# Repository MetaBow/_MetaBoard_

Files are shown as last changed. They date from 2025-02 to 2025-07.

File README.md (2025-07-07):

# MetaBoard™

Buy Now (https://www.paypal.com/ncp/payment/BA7CCF7549GLA)

# MetaBoard

Board_mount-ezgif com-video-to-gif-converter

### Main ICs

- Micro: [nRF53240](https://www.nordicsemi.com/Products/nRF5340) in the [MDBT53](https://www.raytac.com/download/index.php?index_id=60) module
- PMIC (Power manangement IC): [nPM1100](https://www.nordicsemi.com/Products/nPM1100)
- IMU: [BNO086](https://www.ceva-ip.com/wp-content/uploads/2019/10/BNO080_085-Datasheet.pdf)
- Microphone: [MP34DT05-A](https://www.st.com/resource/en/datasheet/mp34dt05-a.pdf)
- Capacitive Touch sensor: [IQS7222A001QNR](https://www.azoteq.com/images/stories/pdf/iqs7222a_datasheet.pdf)
- Haptic Feedback driver: [DRV2605YZFR](https://www.ti.com/lit/ds/symlink/drv2605.pdf)

_newWhatsApp Image 2024-11-21 at 10 35 25 PM

### Inputs/Outputs

- RGB Status LED
- PWR/SOC LED
- 2x Programmable Buttons
- Wake, RST, and Sleep Buttons
- Magnetic USB connector
- Tag-Connect Programming power
- 10 pin IDC programming port (optional)
- 8 pin FPC connector for 5x touch inputs

### Notes:

- The board includes a 10K NTC thermistor for instances where a battery is used that does not contain an NTC. If the battery includes an NTC, the trace MUST be cut (T_CUT).
- The Power LED is unconnected. Solder the solder bridge next to QR code to enable.
- The Device can be placed into a hardware sleep mode by bridging the two SLP test pads. This is also possible by toggling P0.05

# Firmware

Build with nRF Connect SDK 2.4.2 using the VSCode extension. The app is setup as a standalone application. Choose the ```nrf5340dk_nrf5340_cpuapp``` board target and the ```metaboard.overlay``` in your build settings to build for production hardware.

Overlays for other targets have been provided but not recently tested. 

**NEVER** enable DCDC for metabow targets, it WILL brick the board.

The current firmware is designed to output 13 floating-point values via BLE: 4 values representing a quaternion and 3 values each for raw accelerometer, gyroscope, and magnetometer data. The firmware can be modified to stream additional sensor fusion values and support improved audio encoding. Firmware-level integration of the Touch IC and haptic transducer is still pending.

# Unboxing

https://github.com/user-attachments/assets/5d7addd9-e810-4c3d-97cc-f49c3b631e52

The MetaBoard Development Kit includes:
- (1) MetaBoard
- (1) MetaBox
- (1) LiPo Battery
- (1) Magentic 4-pin Charger
- (1) Touch IC Flexboard
- (1) Haptic Capacitor

# MetaBox

MetaBox-ezgif com-video-to-gif-converter

# MetaBoard Bridge



<br>A Python application that bridges Metabow Bluetooth devices with OSC (Open Sound Control), providing comprehensive audio processing, motion data routing, real-time feature extraction, and advanced IMU calibration capabilities.

## Features

### Device Management
- **Bluetooth LE Connection**: connect to multiple Metabow devices simultaneously.
- **Real-time Status Monitoring**: RSSI signal strength, connection quality, and data packet tracking.
- **Connection Recovery**: automatic reconnection handling and failure tracking.

### Advanced Audio Processing
- **Real-time Audio Capture**: high-quality audio processing with configurable parameters.
- **Audio Feature Extraction**: 
  - MFCC (Mel-frequency Cepstral Coefficients)
  - Spectral features (centroid, bandwidth, contrast, rolloff)
  - Chroma features for harmonic analysis
  - Tonnetz for tonal analysis
  - Custom bow force estimation for violin applications
- **Audio Enhancement**: configurable gain, noise gate, and noise reduction.
- **Virtual Audio Output**: VB-Cable integration for routing to audio software.

### Motion Data Processing
- **IMU Data Smoothing**: multiple filtering algorithms including:
  - Moving Average: simple averaging filter that reduces noise by averaging recent samples over a configurable window.
  - Exponential Moving Average (EMA): weighted average that gives more importance to recent samples while maintaining responsiveness.
  - Kalman Filter: optimal estimation filter that uses prediction and measurement models to minimize estimation error.
  - Savitzky-Golay Filter: polynomial smoothing filter that preserves signal features while reducing noise.
  - Median Filter: non-linear filter that replaces each sample with the median of neighboring samples to remove outliers.
  - Gaussian Filter: applies Gaussian weighting to smooth data while preserving important signal characteristics.
- **Axis Calibration**: 3D visualization and calibration tools for proper IMU orientation mapping.
- **Real-time 3D Visualization**: interactive 3D model display with STL file support.

### OSC Integration
- **Flexible Routing System**: individual routes and bundled messages with customizable paths.
- **Multiple Destinations**: independent routing configurations for different applications.
- **Route Discovery**: automatic detection and management of available data streams.
- **Data Logging**: comprehensive JSON export of all OSC data with timestamps.

### System Monitoring
- **Performance Tracking**: real-time CPU usage, memory monitoring, and processing latency.
- **Comprehensive Logging**: floating log window with exportable logs.
- **Audio Monitoring**: peak levels, noise floor, and latency metrics.

## Requirements

### Core Dependencies
```bash
pip install bleak python-osc numpy tkinter pyaudio sounddevice
```

### Advanced Features Dependencies
```bash
pip install scipy scikit-learn librosa matplotlib psutil
```

### 3D Visualization (Optional)
```bash
pip install numpy-stl matplotlib
```

### System Requirements
- **VB-Cable** (for virtual audio routing) - Download from [VB-Audio.com](https://vb-audio.com/Cable/)
- **Python 3.8+** recommended for optimal performance

## Quick Start

1. **Install Dependencies**
   ```bash
   pip install bleak python-osc numpy pyaudio sounddevice scipy scikit-learn librosa matplotlib psutil numpy-stl
   ```

2. **Run the Application**
   ```bash
   python testing_file_floating_calibration_NIME_CPU.py
   ```

3. **Basic Setup**
   - **Add OSC Destinations**: specify target ports (e.g., 6448 for Wekinator).
   - **Scan and Connect**: find and connect to Metabow devices.
   - **Configure Audio Features**: enable desired audio feature extraction.
   - **Set up IMU Processing**: configure axis calibration and smoothing if needed.

4. **Advanced Configuration**
   - **Audio Features**: open "Feature Extraction" to configure MFCC, spectral features, etc.
   - **IMU Calibration**: use "Axis Calibration" for 3D visualization and orientation mapping.
   - **Data Logging**: enable "Save JSON" to capture all OSC data for analysis.

## Technical Architecture

### Audio Processing Pipeline
- **Input**: MP34DT05-A PDM microphone data via Bluetooth.
- **Processing**: real-time feature extraction using librosa and scikit-learn.
- **Output**: individual features or bundled data via OSC.
- **Features Available**:
  - `mfcc`: Mel-frequency cepstral coefficients (13 coefficients)
  - `spectral_centroid`: Brightness indicator
  - `spectral_bandwidth`: Spectral width measure
  - `spectral_contrast`: Harmonic vs. noise ratio
  - `spectral_rolloff`: High-frequency content measure
  - `chroma_*`: Harmonic content analysis (12 bins)
  - `tonnetz`: Tonal space analysis (6 dimensions)
  - `bow_force_*`: Custom violin bow pressure estimation

### Motion Data Processing
- **Raw Data**: 13-component IMU data (quaternion, accelerometer, gyroscope, magnetometer).
- **Calibration**: 3x3 transformation matrices for axis remapping.
- **Smoothing**: configurable filters (Kalman, EMA, Gaussian, etc.).
- **Visualization**: real-time 3D rendering with STL model support.

### OSC Data Structure
```
/metabow/audio                   # Raw PCM audio data
/metabow/audio/mfcc              # MFCC features (array)
/metabow/audio/spectral_centroid # Spectral centroid (float)
/metabow/audio/bow_force_rms     # Bow force estimation (float)
/metabow/motion/quaternion_*     # Quaternion components
/metabow/motion/accelerometer_*  # Accelerometer data
/metabow/motion/gyroscope_*      # Gyroscope data
/metabow/motion/magnetometer_*   # Magnetometer data
```

### Data Logging Format
```json
{
  "metadata": {
    "export_timestamp": 1641234567.89,
    "total_entries": 15000,
    "duration_seconds": 30.5,
    "data_types": ["motion", "audio_feature", "bundle"]
  },
  "data": [
    {
      "timestamp": 1641234567.89,
      "osc_path": "/metabow/audio/mfcc",
      "value": [1.2, -0.5, 0.8, ...],
      "data_type": "audio_feature"
    }
  ]
}
```

## GUI Interface

### Bluetooth Devices Panel
- **Device Control**: scan, connect, disconnect multiple devices.
- **Status Monitoring**: real-time RSSI, signal quality, and data rates.
- **Configuration**: access to IMU smoothing, axis calibration, and audio features.

### OSC Routing Panel
- **Destination Management**: add/remove OSC targets with port configuration.
- **Route Configuration**: individual data stream routing with custom paths.
- **Bundle Management**: combine multiple data streams into single OSC messages.
- **Real-time Monitoring**: view active routes and data flow.

### Audio Controls Panel
- **Virtual Output**: VB-Cable integration for audio software routing.
- **Recording**: WAV file capture with timestamp naming.
- **Processing Controls**: cain, gate threshold, noise reduction.
- **Monitoring**: peak levels, noise floor, latency metrics.

### System Performance Panel
- **CPU Monitoring**: real-time usage tracking and performance warnings.
- **Memory Usage**: process memory consumption and system resources.
- **Data Logging**: JSON export controls and buffer status.

## Advanced Features

### IMU Axis Calibration
- **3D Visualization**: interactive matplotlib-based 3D display.
- **STL Model Support**: Load custom 3D models for visualization.
- **Manual Rotation**: Apply offset rotations for proper orientation.
- **Calibration Presets**: Save and load calibration configurations.

### Audio Feature Extraction
- **Configurable Parameters**: adjust frame sizes, hop lengths, and feature parameters.
- **Real-time Processing**: low-latency feature extraction suitable for live performance.
- **Machine Learning Ready**: features formatted for direct use with Wekinator or custom ML models.

### Performance Optimization
- **CPU Monitoring**: real-time performance tracking and optimization warnings.
- **Processing Statistics**: detailed latency and throughput metrics.
- **Memory Management**: efficient buffering and resource cleanup.

## Use Cases

### Music Performance
- **Real-time Control**: use motion and audio features to control live audio processing.
- **Gesture Recognition**: train ML models on combined motion and audio data.
- **Interactive Systems**: create responsive musical instruments and installations.

### Research Applications
- **Data Collection**: comprehensive logging of multimodal sensor data.
- **Analysis**: JSON export for offline analysis and machine learning.
- **Prototyping**: rapid development of sensor-based interactive systems.

### Educational Projects
- **NIME (New Interfaces for Musical Expression)**: complete toolkit for digital music interface research.
- **Sensor Fusion**: explore combination of audio and motion data.
- **Real-time Systems**: learn about low-latency sensor processing.

## Troubleshooting

### Common Issues
- **VB-Cable Not Detected**: install VB-Cable from official website and restart application.
- **High CPU Usage**: reduce audio feature extraction frame rate or disable unused features.
- **Connection Drops**: check Bluetooth signal strength and reduce distance to device.

### Performance Optimization
- **Reduce Latency**: lower audio buffer sizes and disable unnecessary features.
- **Memory Usage**: adjust data logging buffer sizes and clear logs regularly.
- **3D Visualization**: use lower-resolution STL models for better performance.

## Contributing

We welcome contributions! Please feel free to submit Pull Requests for:
- Additional audio features and analysis algorithms
- Enhanced 3D visualization capabilities
- Performance optimizations
- Documentation improvements
- Bug fixes and stability improvements

## License

This project is open source. Please check the license file for specific terms and conditions.

# Bootloading
### Prerequisites

- snRF Connect app installed on your mobile device
- Programming hardware for initial firmware flashing
- MetaBoard PCB
  
### Initial Setup

#### 1. Flash the Base Firmware
- Erase the device memory completely
- Flash the `merged_domains.hex` file to your MetaBoard

### Performing OTA Updates

#### 2. Transfer Update Package
- Copy the `dfu_application.zip` file to your mobile device

#### 3. Connect & Update

- Open the nRF Connect app on your mobile device
- Scan and connect to your MetaBoard device
- Select the DFU option
- Choose the `dfu_application.zip` file
- Follow the on-screen instructions to complete the update

### Troubleshooting
If you encounter any issues during the update process:

- Ensure the device is sufficiently charged
- Check that you're using the correct update package
- Verify the device is in range and has a stable connection
- Restart the nRF Connect app and try again

### Demo Video
A demonstration video is available showing the complete update process using the nRF Connect app.

Note: Remember that for initial programming, the board should be powered through the programming header, not through the USB magnetic connector. When using the nRF Connect SDK, ensure you're building with version 2.4.2 as specified in the main firmware documentation.

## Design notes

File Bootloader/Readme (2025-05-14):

MetaBow IMU: Bootloader & OTA Update Guide
Overview
This document provides instructions for the bootloader and Over-The-Air (OTA) update functionality for the MetaBow nRF-based IMU device. The bootloader enables wireless firmware updates using Nordic's DFU protocol.
Prerequisites

nRF Connect app installed on your mobile device
Programming hardware to perform initial firmware flashing
MetaBow PCB board

Initial Setup
Flash the Base Firmware
Erase the device memory completely
Flash the merged_domains.hex file to your MetaBow board

Performing OTA Updates
Transfer Update Package
Copy the dfu_application_metabow_ota.zip file to your mobile device

Connect & Update
Open the nRF Connect app on your mobile device
Scan and connect to your MetaBow device
Select the DFU option
Choose the dfu_application_metabow_ota.zip file
Follow the on-screen instructions to complete the update

Verification
After successful update, the device will advertise with a new name to confirm the firmware has been updated.
Reverting to Default Name
To revert to the default MetaBow name:

Perform another DFU update using the dfu_application_metabow.zip file

Troubleshooting
If you encounter any issues during the update process:

Ensure the device is sufficiently charged
Check that you're using the correct update package
Verify the device is in range and has a stable connection
Restart the nRF Connect app and try again

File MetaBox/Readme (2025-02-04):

Here you'll find the 3D printing files for MetaBoard's housing units

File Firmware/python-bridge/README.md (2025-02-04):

## Install dependencies

Python 3 needs to be installed. Whatever version is compatible with the latest version of bleak.

```
pip install -r requirements.txt
```

## Finding Your Device

A few options can be provided to the Python program, like `--scan` which will
scan for BLE devices and list their addresses and names for you.

```
python ble_data_bridge/__init__.py --scan
```

To connect to a device
```
python ble_data_bridge/__init__.py --name "metabow"
```

Or you can provide the address, which is a bit faster because no scan is required:
```
python ble_data_bridge/__init__.py --address "xx:xx:xx:xx:xx:xx"
```

The OSC bridge is running on localhost:5005 sending quaternion data as a float array I,J,K,Real (X,Y,Z,W)

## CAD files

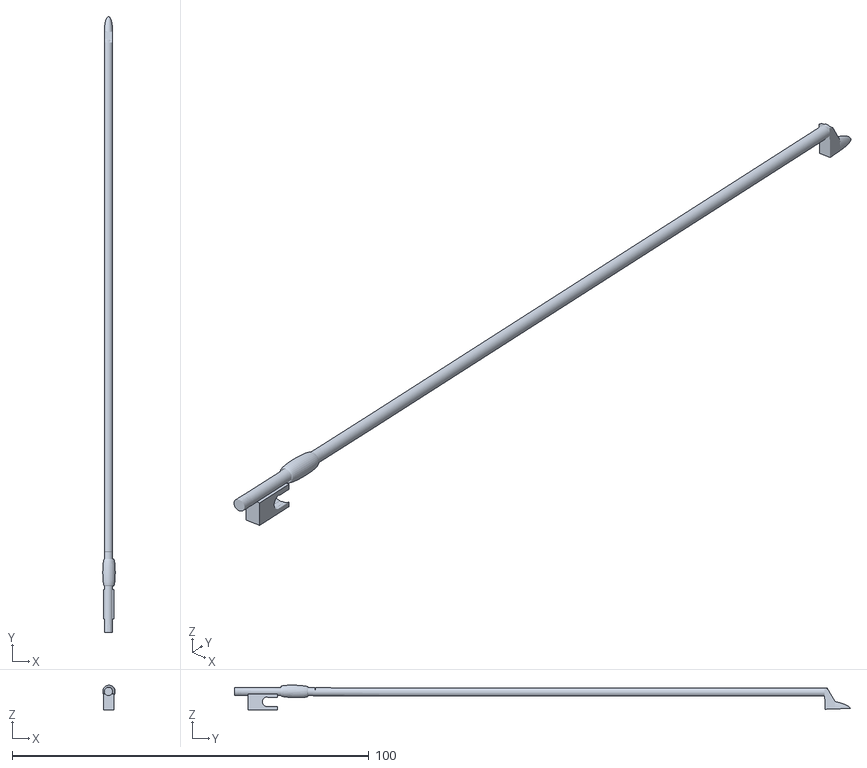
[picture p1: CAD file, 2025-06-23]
Bridge/Violin Bow-export.stl
3.51 x 172.7 x 6.93

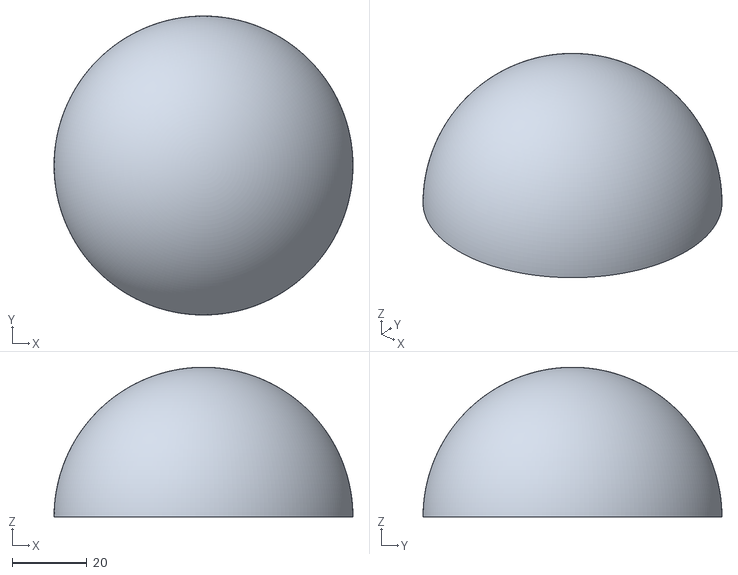
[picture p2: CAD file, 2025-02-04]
MetaBox/1.stl
80.0 x 80.0 x 40.0

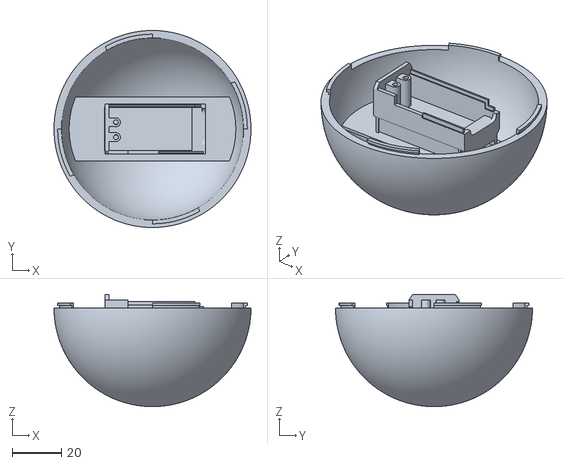
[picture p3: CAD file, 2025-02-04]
MetaBox/box_bottom_12_part0-export.stl
80.0 x 80.0 x 45.6

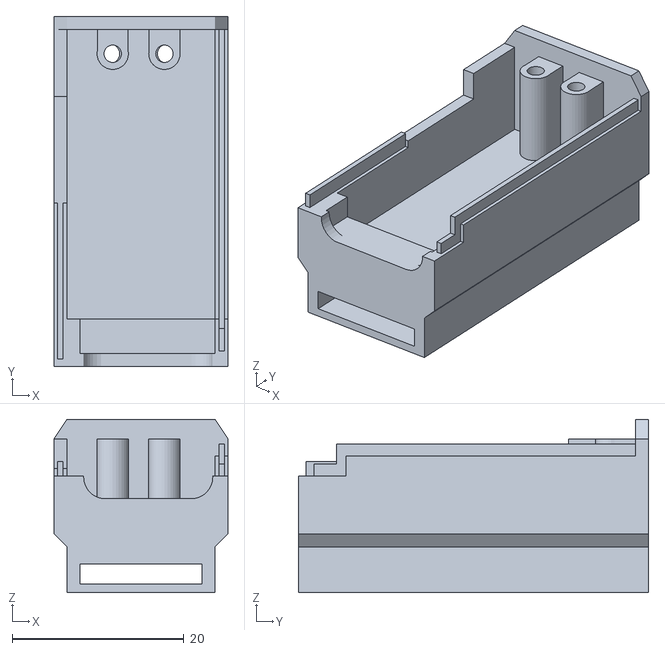
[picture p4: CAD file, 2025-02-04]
MetaBox/box_bottom_12.stl
20.3 x 40.8 x 20.2

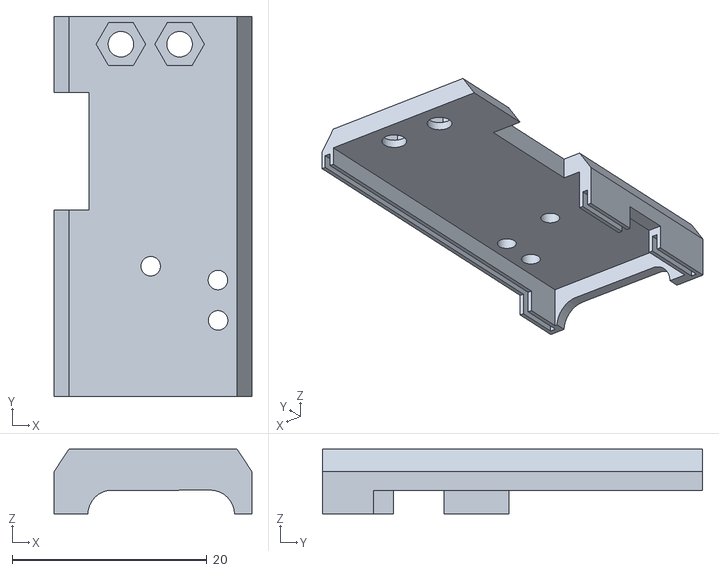
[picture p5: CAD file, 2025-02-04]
MetaBox/box_top_12.stl
20.3 x 39.0 x 6.62

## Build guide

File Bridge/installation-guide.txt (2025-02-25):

# Metabow OSC Bridge Installation Guide

This guide will help you install all dependencies needed for the Metabow OSC Bridge application with Essentia feature extraction.

## Prerequisites

- Python 3.7 or newer
- pip (Python package installer)
- For Windows: Microsoft Visual C++ Build Tools might be required for certain packages
- For macOS: Xcode Command Line Tools
- For Linux: Basic development tools (build-essential, etc.)

## Installation Steps

### 1. Create a virtual environment (recommended)

```bash
# Create a virtual environment
python -m venv metabow-env

# Activate the virtual environment
# On Windows:
metabow-env\Scripts\activate
# On macOS/Linux:
source metabow-env/bin/activate
```

### 2. Install dependencies using requirements.txt

```bash
# Install all required packages
pip install -r requirements.txt
```

### 3. Installing Essentia (if automatic installation fails)

Essentia can sometimes be tricky to install depending on your operating system. If the automatic installation fails, here are platform-specific instructions:

#### Windows

```bash
# Make sure you have Microsoft Visual C++ Build Tools installed
pip install essentia-tensorflow
```

#### macOS

```bash
# Using Homebrew
brew install essentia

# Or using pip with additional flags
pip install essentia --no-binary=essentia
```

#### Linux (Ubuntu/Debian)

```bash
# Install dependencies first
sudo apt-get install build-essential libeigen3-dev libfftw3-dev libavcodec-dev libavformat-dev libavutil-dev libavresample-dev

# Then install essentia
pip install essentia
```

### 4. Verifying Installation

To verify that all dependencies are correctly installed, run:

```python
python -c "import essentia; import numpy; import bleak; import pythonosc; import pyaudio; import sounddevice; print('All dependencies are installed correctly!')"
```

If this command completes without errors, your environment is correctly set up.

## Troubleshooting

### PyAudio Installation Issues

If you encounter issues installing PyAudio:

#### Windows
```bash
pip install pipwin
pipwin install pyaudio
```

#### macOS
```bash
brew install portaudio
pip install pyaudio
```

#### Linux
```bash
sudo apt-get install python3-pyaudio
```

### Essentia-specific Issues

If you encounter issues with Essentia, refer to their official documentation:
https://essentia.upf.edu/documentation/installing.html

For specific algorithms, check:
https://essentia.upf.edu/algorithms_reference.html

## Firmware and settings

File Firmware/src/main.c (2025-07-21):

#include <zephyr/types.h>
#include <zephyr/kernel.h>
#include <zephyr/usb/usb_device.h>

#include <zephyr/device.h>
#include <zephyr/devicetree.h>
#include <soc.h>

#include <zephyr/audio/dmic.h>

#include <zephyr/drivers/sensor.h>

#include <zephyr/bluetooth/bluetooth.h>
#include <zephyr/bluetooth/uuid.h>
#include <zephyr/bluetooth/gatt.h>
#include <zephyr/bluetooth/hci.h>

#include <bluetooth/services/nus.h>

#include <zephyr/drivers/gpio.h>

#include <dk_buttons_and_leds.h>

#include <zephyr/settings/settings.h>

#include <stdio.h>

#include <zephyr/logging/log.h>

// needed to set gain
#include <nrfx_pdm.h>

#include "lz4.h"

// battery monitor includes
#include <zephyr/bluetooth/services/bas.h>
#include "battery_monitor.h"

#include <zephyr/mgmt/mcumgr/transport/smp_bt.h>

//for testing on DK make this 1 and for testing on PCB make it 0
#define TEST_DK_APP				0

#define LOG_MODULE_NAME metabow
LOG_MODULE_REGISTER(LOG_MODULE_NAME);

#define STACKSIZE CONFIG_BT_NUS_THREAD_STACK_SIZE
#define BLE_THREAD_PRIORITY -1
#define IMU_THREAD_PRIORITY 0

#define DEVICE_NAME CONFIG_BT_DEVICE_NAME
#define DEVICE_NAME_LEN	(sizeof(DEVICE_NAME) - 1)

#define RUN_STATUS_LED DK_LED1
#define DFU_STATUS_LED DK_LED2
#
#define RUN_LED_BLINK_INTERVAL 1000

#define CON_STATUS_LED DK_LED2

#define KEY_PASSKEY_ACCEPT DK_BTN1_MSK
#define KEY_PASSKEY_REJECT DK_BTN2_MSK

// #define UART_BUF_SIZE CONFIG_BT_NUS_UART_BUFFER_SIZE
// #define UART_WAIT_FOR_BUF_DELAY K_MSEC(50)
// #define UART_WAIT_FOR_RX CONFIG_BT_NUS_UART_RX_WAIT_TIME

//Audio

#define MAX_SAMPLE_RATE  16000
#define SAMPLE_BIT_WIDTH 16
#define BYTES_PER_SAMPLE sizeof(int16_t)
/* Milliseconds to wait for a block to be read. */
#define READ_TIMEOUT     500

/* Size of a block for N ms of audio data. This dictates our minimum latency */
#define BLOCK_SIZE(_sample_rate, _number_of_channels) \
	((BYTES_PER_SAMPLE * (90) * _number_of_channels))
	// ((BYTES_PER_SAMPLE * (_sample_rate /160) * _number_of_channels))

/* Driver will allocate blocks from this slab to receive audio data into them.
 * Application, after getting a given block from the driver and processing its
 * data, needs to free that block.
 */
#define MAX_BLOCK_SIZE   BLOCK_SIZE(MAX_SAMPLE_RATE, 1)
#define BLOCK_COUNT      32

// Quaternion, Acceleration, Gyroscope, Magnetometer
// #define IMU_DATA_SIZE (4+3+3+3)*sizeof(float)
#define IMU_DATA_SIZE (13)*sizeof(float)
#define IMU_DATA_FLAG_SIZE 1
#define BATTERY_DATA_SIZE sizeof(float)  // Battery SoC as float
#define BLE_BLOCK_SIZE MAX_BLOCK_SIZE+IMU_DATA_SIZE+IMU_DATA_FLAG_SIZE+BATTERY_DATA_SIZE

K_MEM_SLAB_DEFINE(mem_slab, BLE_BLOCK_SIZE, BLOCK_COUNT, 4);

static const struct device *const dmic_dev = DEVICE_DT_GET(DT_NODELABEL(dmic_dev));

const struct device *const imu_dev = DEVICE_DT_GET(DT_NODELABEL(bno085));

#if !DT_NODE_EXISTS(DT_NODELABEL(bno085))
#error "bno08x not defined in device tree"
#endif

K_PIPE_DEFINE(imu_pipe, IMU_DATA_SIZE, 4);

// #define IMU_CLK_NODE DT_ALIAS(imu_clk_sel_1)
// #define IMU_CLK_NODE DT_NODELABEL(imu_clk_sel_1)
// static const struct gpio_dt_spec imu_clk_sel = GPIO_DT_SPEC_GET(IMU_CLK_NODE, gpios);


// #if !DT_NODE_EXISTS(IMU_CLK_NODE)
// #error "Overlay for clk_sel node not properly defined."
// #endif



// BLE

static K_SEM_DEFINE(ble_init_ok, 0, 1);
static K_SEM_DEFINE(imu_init_ok, 0, 1);
static K_SEM_DEFINE(dmic_data_available, 0, BLOCK_COUNT);

// Battery BLE update work
static struct k_work_delayable battery_ble_update_work;


static struct bt_conn *current_conn;
static struct bt_conn *auth_conn;

struct mem_slab_data_t {
	void *fifo_reserved;
	void *data;
	uint16_t len;
};

static K_FIFO_DEFINE(fifo_nus_tx_data);
static K_FIFO_DEFINE(fifo_nus_rx_data);

static const struct bt_data ad[] = {
	BT_DATA_BYTES(BT_DATA_FLAGS, (BT_LE_AD_GENERAL | BT_LE_AD_NO_BREDR)),
	BT_DATA(BT_DATA_NAME_COMPLETE, DEVICE_NAME, DEVICE_NAME_LEN),
};

static const struct bt_data sd[] = {
	BT_DATA_BYTES(BT_DATA_UUID128_ALL, BT_UUID_NUS_VAL),
};

// static const char *phy2str(uint8_t phy)
// {
// 	switch (phy) {
// 	case 0: return "No packets";
// 	case BT_GAP_LE_PHY_1M: return "LE 1M";
// 	case BT_GAP_LE_PHY_2M: return "LE 2M";
// 	case BT_GAP_LE_PHY_CODED: return "LE Coded";
// 	default: return "Unknown";
// 	}
// }

static void connected(struct bt_conn *conn, uint8_t err)
{
    char addr[BT_ADDR_LE_STR_LEN];

    if (err) {
        LOG_ERR("Connection failed (err %u)", err);
        return;
    }

    bt_addr_le_to_str(bt_conn_get_dst(conn), addr, sizeof(addr));
    LOG_INF("Connected %s", addr);

    current_conn = bt_conn_ref(conn);

    dk_set_led_on(CON_STATUS_LED);
    
    // Start battery level updates when connected
    k_work_reschedule(&battery_ble_update_work, K_NO_WAIT);
}

static void disconnected(struct bt_conn *conn, uint8_t reason)
{
    char addr[BT_ADDR_LE_STR_LEN];

    bt_addr_le_to_str(bt_conn_get_dst(conn), addr, sizeof(addr));

    LOG_INF("Disconnected: %s (reason %u)", addr, reason);

    if (auth_conn) {
        bt_conn_unref(auth_conn);
        auth_conn = NULL;
    }

    if (current_conn) {
        bt_conn_unref(current_conn);
        current_conn = NULL;
        dk_set_led_off(CON_STATUS_LED);
        
        // Stop battery updates when disconnected
        k_work_cancel_delayable(&battery_ble_update_work);
    }
}

static bool le_param_req(struct bt_conn *conn, struct bt_le_conn_param *param)
{
	LOG_INF("Connection parameters update request received.\n");
	LOG_INF("Minimum interval: %d, Maximum interval: %d\n",
	       param->interval_min, param->interval_max);
	LOG_INF("Latency: %d, Timeout: %d\n", param->latency, param->timeout);

	return true;
}

static void le_param_updated(struct bt_conn *conn, uint16_t interval,
			     uint16_t latency, uint16_t timeout)
{
	LOG_INF("Connection parameters updated.\n"
	       " interval: %d, latency: %d, timeout: %d\n",
	       interval, latency, timeout);

}

// static void le_phy_updated(struct bt_conn *conn,
// 			   struct bt_conn_le_phy_info *param)
// {
// 	LOG_INF("LE PHY updated: TX PHY %s, RX PHY %s\n",
// 	       phy2str(param->tx_phy), phy2str(param->rx_phy));

// }

// static void le_data_length_updated(struct bt_conn *conn,
// 				   struct bt_conn_le_data_len_info *info)
// {
// 	LOG_INF("LE data len updated: TX (len: %d time: %d)"
// 	       " RX (len: %d time: %d)\n", info->tx_max_len,
// 	       info->tx_max_time, info->rx_max_len, info->rx_max_time);

// }

void mtu_updated(struct bt_conn *conn, uint16_t tx, uint16_t rx)
{
    LOG_INF("Updated MTU: TX: %d RX: %d bytes\n", tx, rx);
}

static struct bt_gatt_cb gatt_callbacks = {
        .att_mtu_updated = mtu_updated
};

// static void exchange_func(struct bt_conn *conn, uint8_t err, struct bt_gatt_exchange_params *params)
// {
// 	if (!err) {
// 		LOG_INF("MTU exchange done");
// 	} else {
// 		LOG_WRN("MTU exchange failed (err %" PRIu8 ")", err);
// 	}
// }

BT_CONN_CB_DEFINE(conn_callbacks) = {
	.connected    = connected,
	.disconnected = disconnected,
	.le_param_req = le_param_req,
	.le_param_updated = le_param_updated,
	// .le_phy_updated = le_phy_updated,
	// .le_data_len_updated = le_data_length_updated,
};

static void bt_receive_cb(struct bt_conn *conn, const uint8_t *const data,
			  uint16_t len)
{
	int err;
	char addr[BT_ADDR_LE_STR_LEN] = {0};

	bt_addr_le_to_str(bt_conn_get_dst(conn), addr, ARRAY_SIZE(addr));

	LOG_INF("Received data from: %s", addr);

}

static struct bt_nus_cb nus_cb = {
	.received = bt_receive_cb,
};

void error(void)
{
	dk_set_leds_state(DK_ALL_LEDS_MSK, DK_NO_LEDS_MSK);

	while (true) {
		/* Spin for ever */
		k_sleep(K_MSEC(1000));
	}
}

static void configure_gpio(void)
{
	int err;

	err = dk_leds_init();
	if (err) {
		LOG_ERR("Cannot init LEDs (err: %d)", err);
	}
}

// Example: Get battery status periodically
void get_battery_status(void)
{
    uint8_t soc = battery_get_soc();
    float voltage = battery_get_voltage();
    uint16_t raw_adc = battery_get_raw_adc();
    
    LOG_INF("Battery Status - SoC: %d%%, Voltage: %.2fV, ADC: %d", 
            soc, voltage, raw_adc);
    
    // You can send this over BLE or use it in your application
}



static void battery_ble_update_handler(struct k_work *work)
{
    uint8_t battery_level = battery_get_soc();
    float battery_voltage = battery_get_voltage();
    
    // Update BLE Battery Service
    int err = bt_bas_set_battery_level(battery_level);
    if (err) {
        LOG_WRN("Failed to update battery level: %d", err);
    } else {
        LOG_INF("BLE Battery Service updated: %d%% (%.2fV)", battery_level, battery_voltage);
    }
    
    // Reschedule for next update
    k_work_reschedule(&battery_ble_update_work, K_MSEC(BATTERY_SERVICE_UPDATE_INTERVAL_MS));
}


int main(void)
{
	int blink_status = 0;
	int err = 0;
	int ret;

	
#if (TEST_DK_APP == 0)
	if (!device_is_ready(dmic_dev)) {
		LOG_ERR("%s is not ready", dmic_dev->name);
		return 0;
	}

	if (!device_is_ready(imu_dev)) {
		LOG_ERR("Device %s is not ready\n", imu_dev->name);
		return 0;
	}

	k_sem_give(&imu_init_ok);

	struct pcm_stream_cfg stream = {
		.pcm_width = SAMPLE_BIT_WIDTH,
		.mem_slab  = &mem_slab,
	};

	struct dmic_cfg cfg = {
		.io = {
			/* These fields can be used to limit the PDM clock
			 * configurations that the driver is allowed to use
			 * to those supported by the microphone.
			 */
			.min_pdm_clk_freq = 1200000,
			.max_pdm_clk_freq = 3200000,
			.min_pdm_clk_dc   = 40,
			.max_pdm_clk_dc   = 60,
		},
		.streams = &stream,
		.channel = {
			.req_num_streams = 1,
		},
	};

	cfg.channel.req_num_chan = 1;
	cfg.channel.req_chan_map_lo = dmic_build_channel_map(0, 0, PDM_CHAN_LEFT);
	cfg.streams[0].pcm_rate = MAX_SAMPLE_RATE;
	cfg.streams[0].block_size = BLOCK_SIZE(cfg.streams[0].pcm_rate, cfg.channel.req_num_chan);

	LOG_INF("PCM output rate: %u, channels: %u",
		cfg.streams[0].pcm_rate, cfg.channel.req_num_chan);

	ret = dmic_configure(dmic_dev, &cfg);
	if (ret < 0) {
		LOG_ERR("Failed to configure the driver: %d", ret);
		return ret;
	}
	
	nrf_pdm_gain_set(NRF_PDM0, NRF_PDM_GAIN_MAXIMUM, NRF_PDM_GAIN_MAXIMUM);
#endif
	configure_gpio();

	// err = uart_init();
	// if (err) {
	// 	error();
	// }

	err = bt_enable(NULL);
	if (err) {
		error();
	}
	// /* ---------- expose mcumgr SMP DFU service -------------- */
	smp_bt_register();        /* init Secure DFU OTA */


	LOG_INF("Bluetooth initialized");

	k_sem_give(&ble_init_ok);

	if (IS_ENABLED(CONFIG_SETTINGS)) {
		settings_load();
	}

	err = bt_nus_init(&nus_cb);
	if (err) {
		LOG_ERR("Failed to initialize NUS service (err: %d)", err);
		return 0;
	}

	k_sleep(K_MSEC(500));
	// Initialize battery monitoring
	err = battery_monitor_init();
	if (err) {
		LOG_ERR("Battery monitor init failed: %d", err);
		// Continue anyway, battery monitoring is not critical
	}

	    // Initialize battery BLE update work
    k_work_init_delayable(&battery_ble_update_work, battery_ble_update_handler);

    // Get initial battery reading and set it
    k_sleep(K_MSEC(100)); // Small delay to ensure battery monitor has a reading
    uint8_t initial_battery = battery_get_soc();
    err = bt_bas_set_battery_level(initial_battery);
    if (err) {
        LOG_WRN("Failed to set initial battery level: %d", err);
    } else {
        LOG_INF("Initial battery level set to %d%%", initial_battery);
    }

	err = bt_le_adv_start(BT_LE_ADV_CONN, ad, ARRAY_SIZE(ad), sd, ARRAY_SIZE(sd));
	if (err) {
		LOG_ERR("Advertising failed to start (err %d)", err);
		return 0;
	}

	bt_gatt_cb_register(&gatt_callbacks);

	//===TESTING=======================================
	// if (!gpio_is_ready_dt(&imu_clk_sel)) {
	// 	return 0;
	// }

	// ret = gpio_pin_configure_dt(&imu_clk_sel, GPIO_OUTPUT_INACTIVE);
	// if (ret < 0) {
	// 	return 0;
	// }

	//==================================================
#if (TEST_DK_APP == 0)
	ret = dmic_trigger(dmic_dev, DMIC_TRIGGER_START);
	if (ret < 0) {
		LOG_ERR("START trigger failed: %d", ret);
		return ret;
	}
#endif
	

	
	for (;;) {

		// battery status
		// get_battery_status();
		
#if (TEST_DK_APP == 0)
		// dk_set_led(RUN_STATUS_LED, (++blink_status) % 2);
		// k_sleep(K_MSEC(RUN_LED_BLINK_INTERVAL));
#else
		dk_set_led(DFU_STATUS_LED, (++blink_status) % 2);
		k_sleep(K_MSEC(RUN_LED_BLINK_INTERVAL));
#endif

		// ---------------------------------------------
#if (TEST_DK_APP == 0)

		void *buffer;
		uint32_t size;
#if defined(DEBUG_PRINT)
		LOG_INF("mem_slabs in use before next dmic read: %d", k_mem_slab_num_used_get(&mem_slab));
#endif
		ret = dmic_read(dmic_dev, 0, &buffer, &size, READ_TIMEOUT);
		if (ret < 0) {
			LOG_ERR("dmic read failed: %d", ret);
			return ret;
		}
		
		struct mem_slab_data_t *tx = k_malloc(sizeof(*tx));
		if (tx == NULL) {
			LOG_ERR("unable to allocate memory for mem_slab_data_t %d", ret);
			return ret;
		}
		tx->len = size;
		tx->data = buffer;
		k_fifo_put(&fifo_nus_rx_data, tx);
		// LOG_INF("dmic buffer size: %d", size);
#endif

	}
#if (TEST_DK_APP == 0)

	ret = dmic_trigger(dmic_dev, DMIC_TRIGGER_STOP);
	if (ret < 0) {
		LOG_ERR("STOP trigger failed: %d", ret);
		return ret;
	}
#endif

}

void ble_write_thread(void)
{
    /* Don't go any further until BLE is initialized */
    k_sem_take(&ble_init_ok, K_FOREVER);
    int rc;
    
    for (;;) {
        struct mem_slab_data_t *buf = k_fifo_get(&fifo_nus_rx_data, K_FOREVER);
        if(buf != NULL){
            void *buffer = buf->data;
            uint32_t size = BLE_BLOCK_SIZE;

            // Get IMU data
            size_t bytes_read;
            rc = k_pipe_get(&imu_pipe, (uint8_t*)buffer+MAX_BLOCK_SIZE, IMU_DATA_SIZE, &bytes_read,
                    IMU_DATA_SIZE, K_USEC(50));
            uint8_t imu_data_flag = 0;
            if((rc < 0) && (bytes_read == 0)){
                imu_data_flag = 0;
            }else if ((rc < 0) || (bytes_read < IMU_DATA_SIZE)) {
                LOG_ERR("Failed to get all IMU data from pipe, read: %d", bytes_read);
                imu_data_flag = 0;
            }else{
                imu_data_flag = 1;
            }
            
            // Set IMU data flag
            *((uint8_t*)buffer + MAX_BLOCK_SIZE + IMU_DATA_SIZE) = imu_data_flag;
            
            // Add battery SoC data
            float battery_soc = (float)battery_get_soc();  // Get current battery percentage
            memcpy((uint8_t*)buffer + MAX_BLOCK_SIZE + IMU_DATA_SIZE + IMU_DATA_FLAG_SIZE, 
                   &battery_soc, BATTERY_DATA_SIZE);
            
            LOG_INF("Sending BLE data with Battery SoC: %.1f%%", battery_soc);

            const size_t max_packet_size = bt_nus_get_mtu(current_conn);
            LOG_INF("BLE audio data buffer size: %d, MTU size: %d", size, max_packet_size);
            
            if (size > max_packet_size){
                for (uint32_t sendIndex = 0; sendIndex < size; sendIndex += max_packet_size) {
                    uint32_t chunkLength = sendIndex + max_packet_size < size
                            ? max_packet_size
                            : (size - sendIndex);
                    if (bt_nus_send(current_conn, (uint8_t*) buffer + sendIndex, chunkLength)) {
                        // LOG_WRN("Failed to send audio data over BLE connection");
                    }
                }
            }else{
                if (bt_nus_send(current_conn, (uint8_t*) buffer, size)) {
                    // LOG_WRN("Failed to send audio data over BLE connection");
                }
            }
            k_mem_slab_free(&mem_slab, &buffer);
            k_free(buf);
        }
    }
}

void imu_fetch_thread(void)
{
	k_sem_take(&imu_init_ok, K_FOREVER);
	// todo add out of tree sensor_channel include to define custom channels
	#define SENSOR_CHAN_ROTATION_VEC_IJKR 61
	struct sensor_value quat[4];
	struct sensor_value accel[3];
	struct sensor_value gyro[3];
	struct sensor_value mag[3];
	float imu_data[IMU_DATA_SIZE/sizeof(float)];
	size_t bytes_written;
	int rc;
	for (;;) {
		
		sensor_sample_fetch(imu_dev);

		rc = sensor_channel_get(imu_dev, SENSOR_CHAN_ROTATION_VEC_IJKR, quat);
		if (rc < 0){LOG_ERR("could not get ROTATION_VEC data: %d", rc);continue;}
		rc = sensor_channel_get(imu_dev, SENSOR_CHAN_ACCEL_XYZ, accel);
		if (rc < 0){LOG_ERR("could not get ACCEL_XYZ data: %d", rc);continue;}
		rc = sensor_channel_get(imu_dev, SENSOR_CHAN_GYRO_XYZ, gyro);
		if (rc < 0){LOG_ERR("could not get GYRO_XYZ data: %d", rc);continue;}
		rc = sensor_channel_get(imu_dev, SENSOR_CHAN_MAGN_XYZ, mag);
		if (rc < 0){LOG_ERR("could not get MAGN_XYZ data: %d", rc);continue;}

		// TBD should become a struct
		imu_data[0] = (float)sensor_value_to_double(&quat[0]);
		imu_data[1] = (float)sensor_value_to_double(&quat[1]);
		imu_data[2] = (float)sensor_value_to_double(&quat[2]);
		imu_data[3] = (float)sensor_value_to_double(&quat[3]);

		imu_data[4] = (float)sensor_value_to_double(&accel[0]);
		imu_data[5] = (float)sensor_value_to_double(&accel[1]);
		imu_data[6] = (float)sensor_value_to_double(&accel[2]);

		imu_data[7] = (float)sensor_value_to_double(&gyro[0]);
		imu_data[8] = (float)sensor_value_to_double(&gyro[1]);
		imu_data[9] = (float)sensor_value_to_double(&gyro[2]);

		imu_data[10] = (float)sensor_value_to_double(&mag[0]);
		imu_data[11] = (float)sensor_value_to_double(&mag[1]);
		imu_data[12] = (float)sensor_value_to_double(&mag[2]);

		rc = k_pipe_put(&imu_pipe, imu_data, IMU_DATA_SIZE, &bytes_written, IMU_DATA_SIZE, K_FOREVER);
		
		if (rc < 0) {
            LOG_ERR("Failed to put IMU data into pipe: %d", rc);
        } else if (bytes_written < IMU_DATA_SIZE) {
            LOG_ERR("Only %d bytes written to IMU pipe", bytes_written);
        }
#if defined(DEBUG_PRINT)
		LOG_INF("Rotation: I: %f, J: %f, K: %f, R: %f", sensor_value_to_double(&quat[0]), sensor_value_to_double(&quat[1]), sensor_value_to_double(&quat[2]), sensor_value_to_double(&quat[3]));
		LOG_INF("Acceleration: X: %f, Y: %f, Z: %f", sensor_value_to_double(&accel[0]), sensor_value_to_double(&accel[1]), sensor_value_to_double(&accel[2]));
		LOG_INF("Gyroscope: X: %f, Y: %f, Z: %f", sensor_value_to_double(&gyro[0]), sensor_value_to_double(&gyro[1]), sensor_value_to_double(&gyro[2]));
		LOG_INF("Magnetometer: X: %f, Y: %f, Z: %f", sensor_value_to_double(&mag[0]), sensor_value_to_double(&mag[1]), sensor_value_to_double(&mag[2]));
#endif
		// bt_nus_send(current_conn, (uint8_t*) quat, sizeof(quat));
		k_sleep(K_USEC(200));
	}
}
#if (TEST_DK_APP == 0)
K_THREAD_DEFINE(ble_write_thread_id, STACKSIZE, ble_write_thread, NULL, NULL,
		NULL, BLE_THREAD_PRIORITY, 0, 0);

K_THREAD_DEFINE(imu_fetch_thread_id, 4096, imu_fetch_thread, NULL, NULL,
		NULL, IMU_THREAD_PRIORITY, 0, 0);
#endif

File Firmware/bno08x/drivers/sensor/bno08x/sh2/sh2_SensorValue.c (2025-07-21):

/*
 * Copyright 2015-21 CEVA, Inc.
 *
 * Licensed under the Apache License, Version 2.0 (the "License");
 * you may not use this file except in compliance with the License and 
 * any applicable agreements you may have with CEVA, Inc.
 * You may obtain a copy of the License at
 *
 *   http://www.apache.org/licenses/LICENSE-2.0
 *
 * Unless required by applicable law or agreed to in writing, software
 * distributed under the License is distributed on an "AS IS" BASIS,
 * WITHOUT WARRANTIES OR CONDITIONS OF ANY KIND, either express or implied.
 * See the License for the specific language governing permissions and
 * limitations under the License.
 */

/*
 * BNO080 Sensor Event decoding
 */

#include "sh2_SensorValue.h"
#include "sh2_err.h"
#include "sh2_util.h"

#include <stdio.h>

#define SCALE_Q(n) (1.0f / (1 << n))

const float scaleRadToDeg = 180.0f / 3.14159265358f;

// ------------------------------------------------------------------------
// Forward declarations

static int decodeRawAccelerometer(sh2_SensorValue_t *value, const sh2_SensorEvent_t *event);
static int decodeAccelerometer(sh2_SensorValue_t *value, const sh2_SensorEvent_t *event);
static int decodeLinearAcceleration(sh2_SensorValue_t *value, const sh2_SensorEvent_t *event);
static int decodeGravity(sh2_SensorValue_t *value, const sh2_SensorEvent_t *event);
static int decodeRawGyroscope(sh2_SensorValue_t *value, const sh2_SensorEvent_t *event);
static int decodeGyroscopeCalibrated(sh2_SensorValue_t *value, const sh2_SensorEvent_t *event);
static int decodeGyroscopeUncal(sh2_SensorValue_t *value, const sh2_SensorEvent_t *event);
static int decodeRawMagnetometer(sh2_SensorValue_t *value, const sh2_SensorEvent_t *event);
static int decodeMagneticFieldCalibrated(sh2_SensorValue_t *value, const sh2_SensorEvent_t *event);
static int decodeMagneticFieldUncal(sh2_SensorValue_t *value, const sh2_SensorEvent_t *event);
static int decodeRotationVector(sh2_SensorValue_t *value, const sh2_SensorEvent_t *event);
static int decodeGameRotationVector(sh2_SensorValue_t *value, const sh2_SensorEvent_t *event);
static int decodeGeomagneticRotationVector(sh2_SensorValue_t *value, const sh2_SensorEvent_t *event);
static int decodePressure(sh2_SensorValue_t *value, const sh2_SensorEvent_t *event);
static int decodeAmbientLight(sh2_SensorValue_t *value, const sh2_SensorEvent_t *event);
static int decodeHumidity(sh2_SensorValue_t *value, const sh2_SensorEvent_t *event);
static int decodeProximity(sh2_SensorValue_t *value, const sh2_SensorEvent_t *event);
static int decodeTemperature(sh2_SensorValue_t *value, const sh2_SensorEvent_t *event);
static int decodeReserved(sh2_SensorValue_t *value, const sh2_SensorEvent_t *event);
static int decodeTapDetector(sh2_SensorValue_t *value, const sh2_SensorEvent_t *event);
static int decodeStepDetector(sh2_SensorValue_t *value, const sh2_SensorEvent_t *event);
static int decodeStepCounter(sh2_SensorValue_t *value, const sh2_SensorEvent_t *event);
static int decodeSignificantMotion(sh2_SensorValue_t *value, const sh2_SensorEvent_t *event);
static int decodeStabilityClassifier(sh2_SensorValue_t *value, const sh2_SensorEvent_t *event);
static int decodeShakeDetector(sh2_SensorValue_t *value, const sh2_SensorEvent_t *event);
static int decodeFlipDetector(sh2_SensorValue_t *value, const sh2_SensorEvent_t *event);
static int decodePickupDetector(sh2_SensorValue_t *value, const sh2_SensorEvent_t *event);
static int decodeStabilityDetector(sh2_SensorValue_t *value, const sh2_SensorEvent_t *event);
static int decodePersonalActivityClassifier(sh2_SensorValue_t *value, const sh2_SensorEvent_t *event);
static int decodeSleepDetector(sh2_SensorValue_t *value, const sh2_SensorEvent_t *event);
static int decodeTiltDetector(sh2_SensorValue_t *value, const sh2_SensorEvent_t *event);
static int decodePocketDetector(sh2_SensorValue_t *value, const sh2_SensorEvent_t *event);
static int decodeCircleDetector(sh2_SensorValue_t *value, const sh2_SensorEvent_t *event);
static int decodeHeartRateMonitor(sh2_SensorValue_t *value, const sh2_SensorEvent_t *event);
static int decodeArvrStabilizedRV(sh2_SensorValue_t *value, const sh2_SensorEvent_t *event);
static int decodeArvrStabilizedGRV(sh2_SensorValue_t *value, const sh2_SensorEvent_t *event);
static int decodeGyroIntegratedRV(sh2_SensorValue_t *value, const sh2_SensorEvent_t *event);
static int decodeIZroRequest(sh2_SensorValue_t *value, const sh2_SensorEvent_t *event);
static int decodeRawOptFlow(sh2_SensorValue_t *value, const sh2_SensorEvent_t *event);
static int decodeDeadReckoningPose(sh2_SensorValue_t *value, const sh2_SensorEvent_t *event);
static int decodeWheelEncoder(sh2_SensorValue_t *value, const sh2_SensorEvent_t *event);

// ------------------------------------------------------------------------
// Public API
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
